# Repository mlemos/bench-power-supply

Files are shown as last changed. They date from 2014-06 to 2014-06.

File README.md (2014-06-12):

#Fonte de Alimentação para Bancada#

Fonte de Alimentação para Bancada

Este é o projeto de uma fonte linear para bancada. É uma fonte bem simples utilizando um regulador LM317 e que pode fornecer tensões entre 3 e 15 Volts com corrente máxima de até 1A.

##Dicas para Montagem##

No diagrama você não verá alguns componentes importantes da fonte, pois usei o diagrama do Eagle para montar a placa de circuito impresso com alguns conectores para componentes que ficaram fora da placa. Neste caso você verá, no diagrama e na placa, os conectores para a ligação destes componentes.

Fiz isto pois pretendo montar a fonte numa caixa de projetos para que fique bem profissional. Veja na foto uma versão quase final do projeto.

Os componentes que ficam de foram sõa:

* Transformador AC 127 para 12+12 2A
* Potenciômetro 5K ohms
* Regulador de tensão LM317
* LED indicador de funcionamento
* Bourne de saída (um vermelho e um preto)

Outro cuidado fundamental é o de colocar um belo dissipador de calor no LM317. Não sei direito como dimensionar este componente, coloquei o maior que consegui encontrar e que dava para ser montado na traseira da caixa que estou usando na montagem.

##E mais...##

Na foto você verá que estou montando duas fontes e colocando na mesma caixa.

E também coloquei coisas como uma chave geral para ligar e desligar a alimentação da rede.

E uma chave para cada fonte que corta a saída da fonte. Assim você pode cortar a alimentação de cada fonte individualmente.

E também adicionei dois medidores digitais de corrente e tensão.

Por enquanto é isto... espero que gostem!

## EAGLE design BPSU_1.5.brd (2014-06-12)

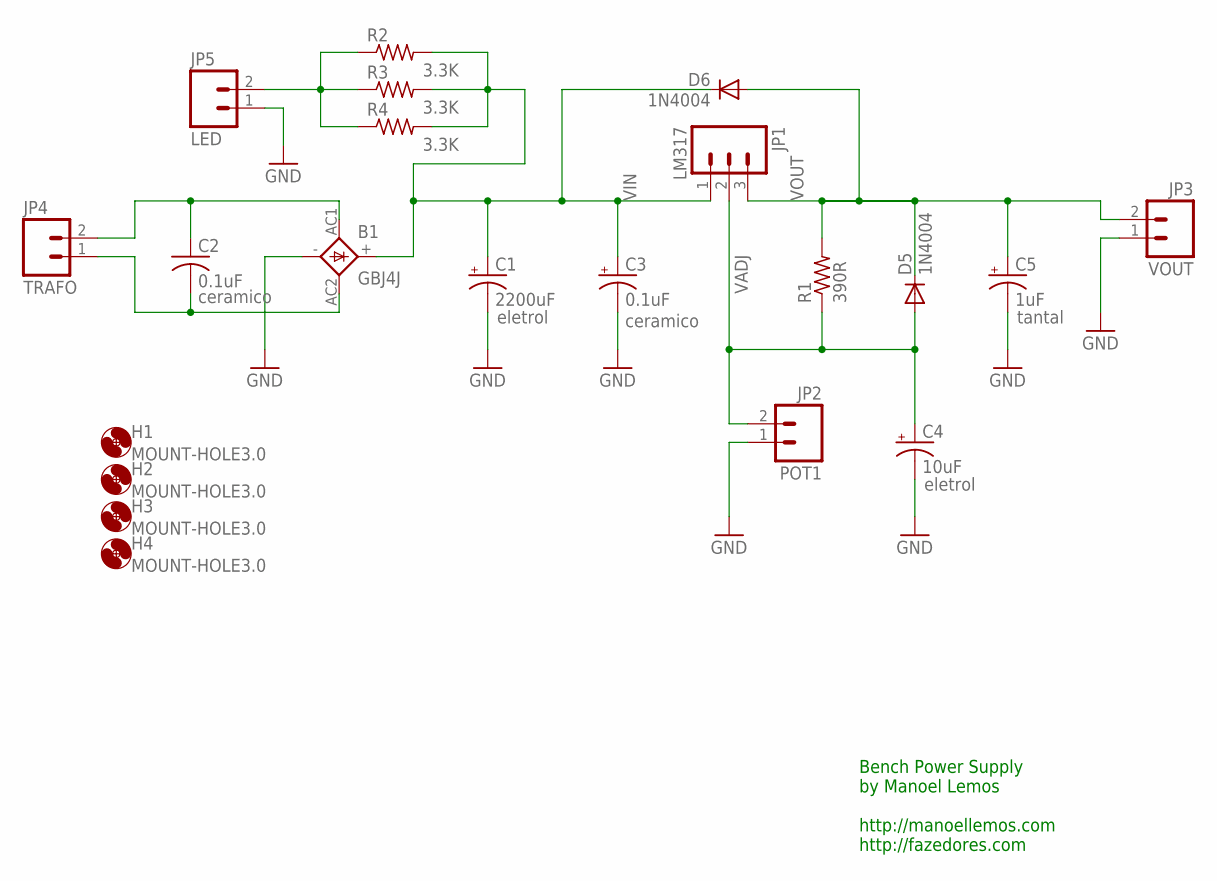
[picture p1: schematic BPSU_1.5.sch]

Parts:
B1: GBJ4J; GBJ
C1: 2200uF; E7,5-18
C2: 0.1uF; C075-063X106
C3: 0.1uF; E3,5-8
C4: 10uF; E3,5-8
C5: 1uF; E3,5-8
D5, D6: 1N4004; DO41-10
H1, H2, H3, H4: MOUNT-HOLE3.0; 3,0
JP1: LM317; 1X03_LONGPADS
JP2: POT1; 1X02_LONGPADS_ML
JP3: VOUT; 1X02_LONGPADS_ML
JP4: TRAFO; 1X02_LONGPADS_ML
JP5: LED; 1X02_LONGPADS_ML
R1: 390R; 0204/7
R2, R3, R4: 3.3K; 0204/7

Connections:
GND: B1.-, C1.-, C3.-, C4.-, C5.-, JP2.1, JP3.1, JP5.1
unnamed: JP5.2, R2.1, R3.1, R4.1
unnamed: B1.AC1, C2.1, JP4.2
unnamed: B1.AC2, C2.2, JP4.1
VADJ: C4.+, D5.A, JP1.2, JP2.2, R1.1
VIN: B1.+, C1.+, C3.+, D6.C, JP1.1, R2.2, R3.2, R4.2
VOUT: C5.+, D5.C, D6.A, JP1.3, JP3.2, R1.2

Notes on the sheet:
eletrol
ceramico
tantal
Bench Power Supply by Manoel Lemos http://manoellemos.com http://fazedores.com

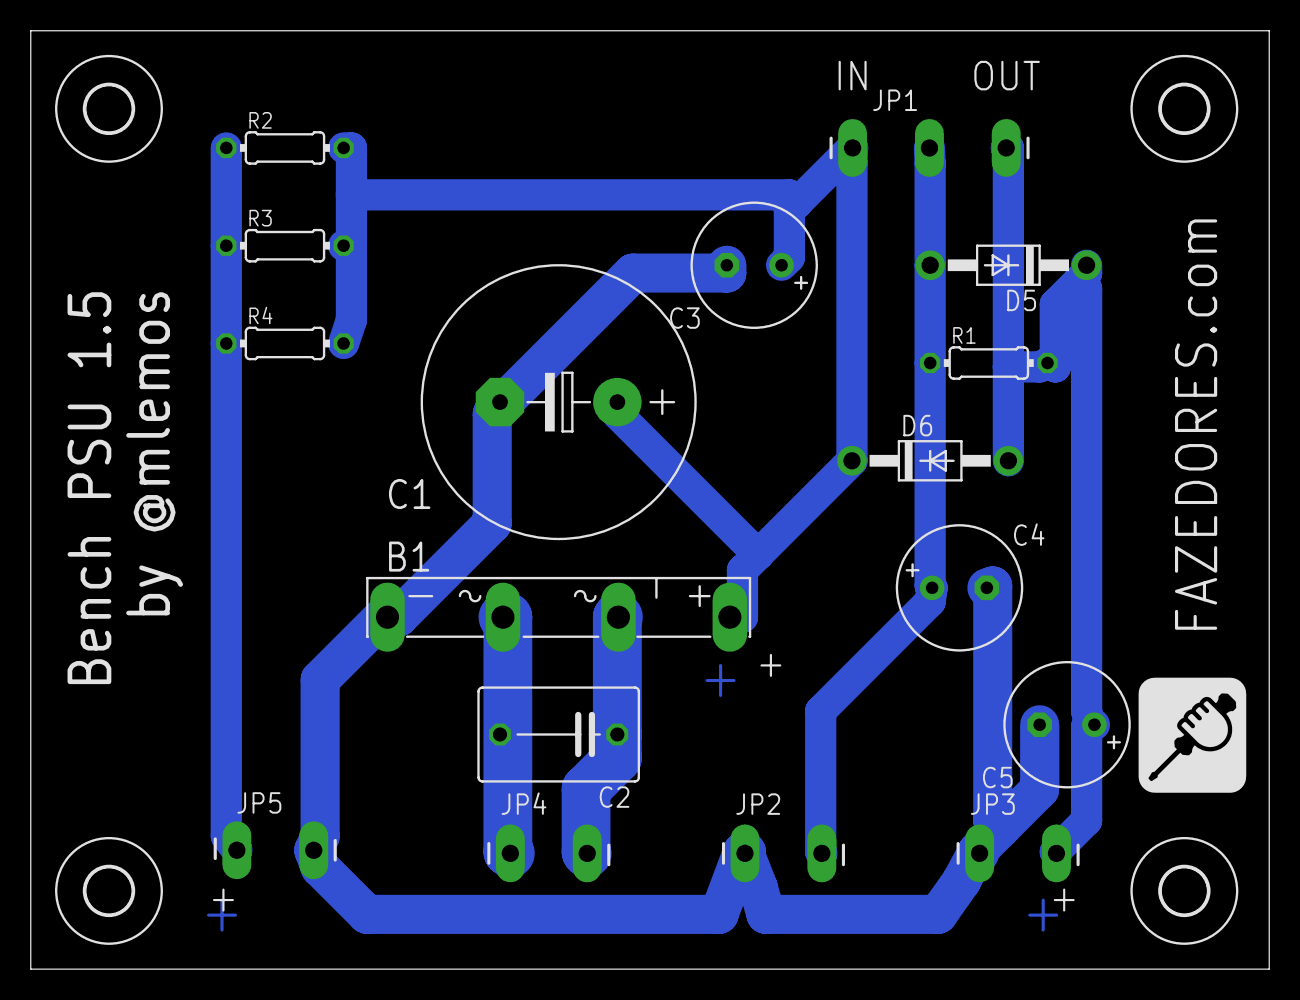
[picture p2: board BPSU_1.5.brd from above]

Board: 2 copper layers, 80.4 x 61.0 mm, 22 parts (0 on the bottom side), 7 nets.

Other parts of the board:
U$5: LOGO_FAZEDORES_BIG_TSILK

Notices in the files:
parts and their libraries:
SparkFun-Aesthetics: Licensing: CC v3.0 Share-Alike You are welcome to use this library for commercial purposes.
